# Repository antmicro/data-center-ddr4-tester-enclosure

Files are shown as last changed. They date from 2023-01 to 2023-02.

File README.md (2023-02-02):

# Data Center DDR4 Tester Enclosure

Copyright (c) 2022-2023 [Antmicro](https://antmicro.com)

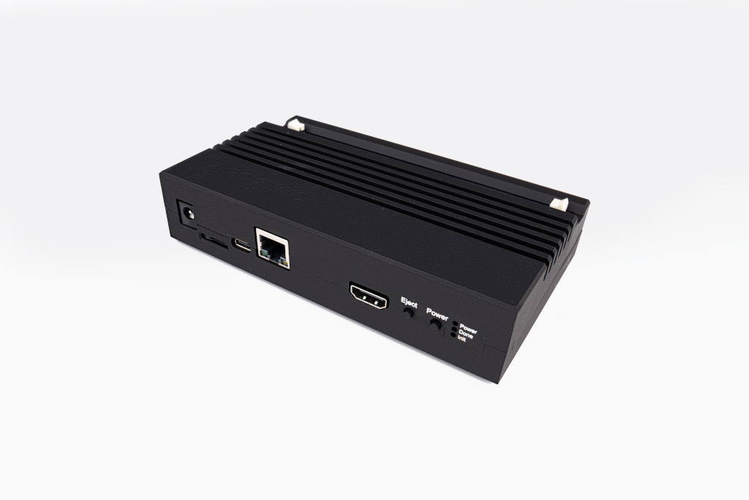
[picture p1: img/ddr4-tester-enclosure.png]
Data Center DDR4 Tester Enclosure


## Overview

This repository contains open hardware mechanical design files for an enclosure matching the [Data Center DRAM Tester](https://github.com/antmicro/data-center-dram-tester) PCBs.
The enclosure has been optimized mechanically for PCBs in revision 1.2.0.
There are three major parts of the enclosure:

* base - supporting the DRAM tester PCB from the bottom,
* front lid - installed above the FPGA, connectors and power supply section of the PCB,
* back lid - installed around the DDR4 RDIMM module slot.

Additionally there are two mechanical components exposing the LEDs installed on the DRAM tester PCB:

* PMMA lightpipe - custom lightpipe laser-cut from acrylic glass (PMMA),
* lightpipe separator - groups LED lightpipes and keeps the custom PMMA lightpipes from stray light.

## Repository structure

The main repository directory contains a LICENSE and a README.
The remaining files are stored in the following directories:

* `step` - contains the enclosure parts published as STEP files 
* `stl` - contains the enclosure parts for 3D printing in STL format
* `dxf` - contains the production file for PMMA laser cutting
* `img` - contains graphics for this README

## Key features

* Dust protection
* Improves passive cooling of the FPGA 
* Optimized for desktop usage

## License

[Apache-2.0](LICENSE)

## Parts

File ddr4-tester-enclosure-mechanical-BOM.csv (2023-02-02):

Description | Quantity | Name | Finish | Material | Manufacturer | MPN
Enclosure base | 1 | base | Black-anodized | Aluminium | Custom-CNC milled | -
Enclosure back lid | 1 | back_lid | Black-anodized | Aluminium | Custom-CNC milled | -
Enclosure front lid | 1 | front_lid | Black-anodized | Aluminium | Custom-CNC milled | -
Light guides | 6 | PMMA_lightpipe | Transparent or frosted | PMMA | Custom-Laser cut | -
Light guide separator | 1 | lightpipe_separator | Any | PLA, PETG,ABS | Custon -3D print | -
Enclosure bolts | 4 | Bolt M3x8 | Black-anodized | Steel | KRAFTBERG | M3X8/D7985B
Light guide separator bolts | 2 | Bolt M3x4 | Black-anodized | Steel | KRAFTBERG | M3X4/D7985B
Status diodes light pipe | 1 | Light pipe | - | PC clear | Mentor | 1296.2013
Rubber legs | 4 | rubber legs | black | Rubber | FIX&FASTEN | RF8-2A
Thermal paste | 1 | - | - | - | - | -

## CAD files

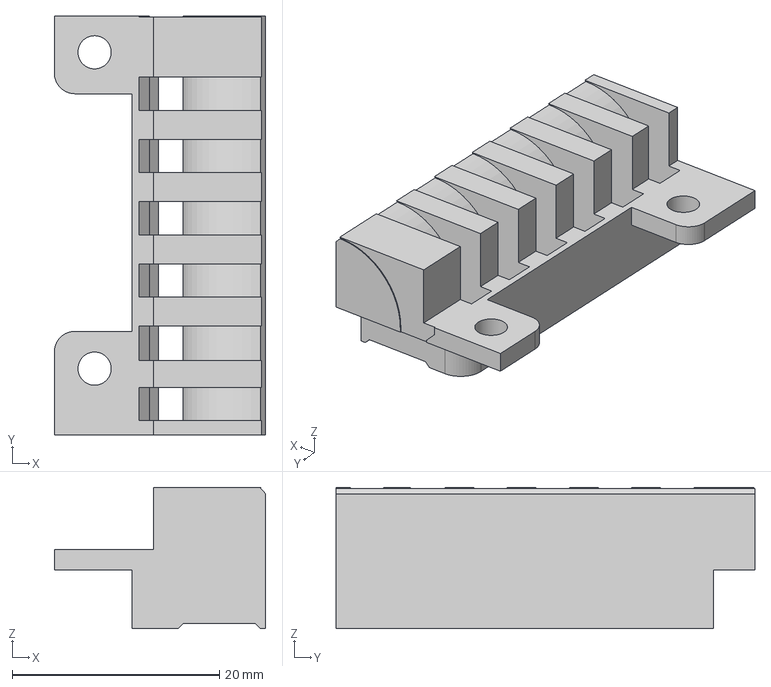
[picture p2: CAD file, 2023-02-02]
step/lightpipe_separator.step
20.4 x 40.4 x 13.6 mm

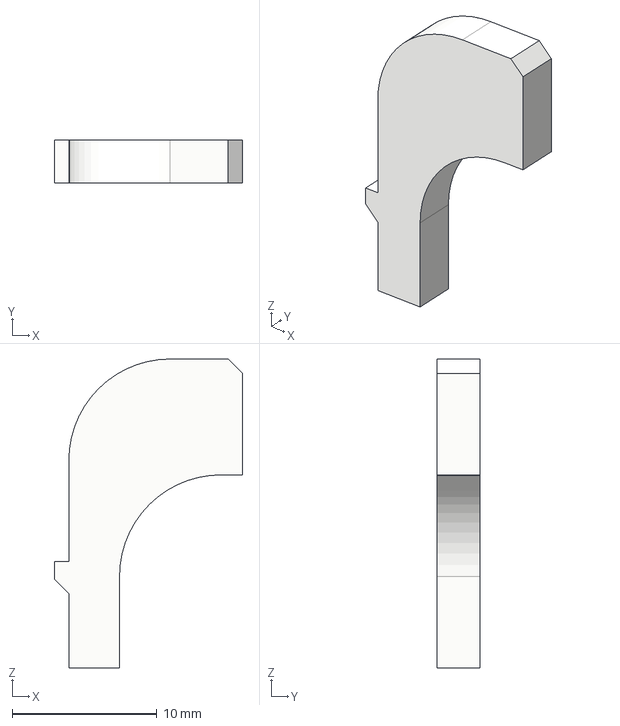
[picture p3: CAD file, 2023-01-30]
step/PMMA_lightpipe.step
13.0 x 3.00 x 21.3 mm

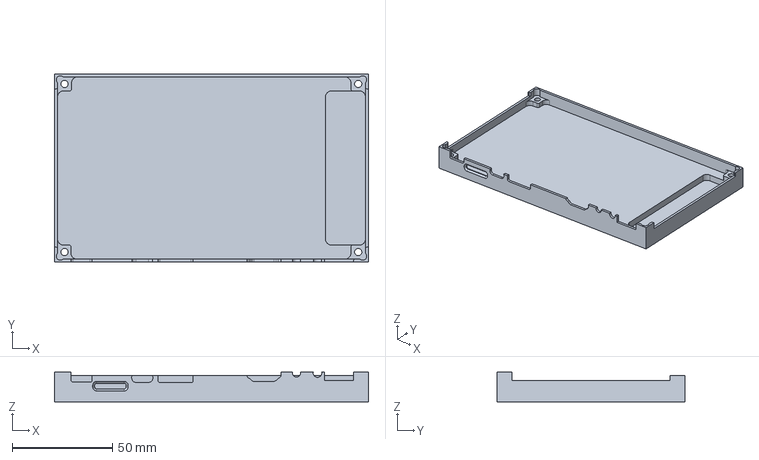
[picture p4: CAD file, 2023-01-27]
step/base.step
156.9 x 94.0 x 14.8 mm

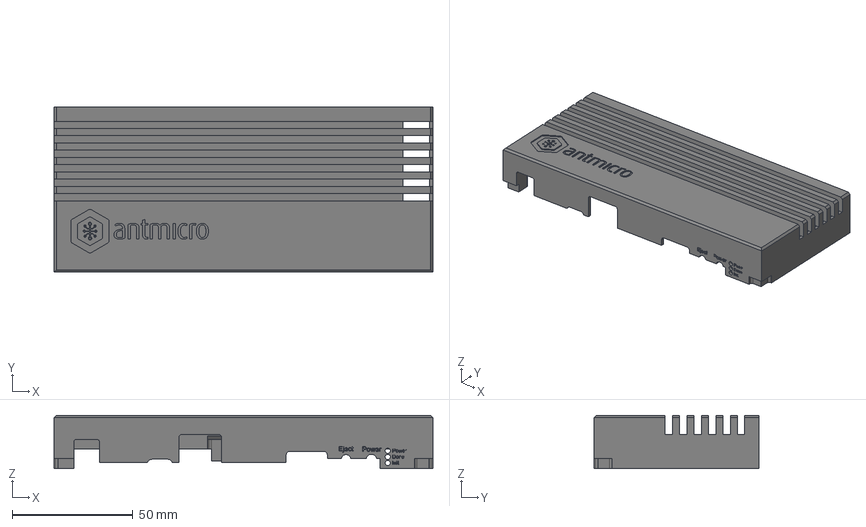
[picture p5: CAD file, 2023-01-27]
step/front_lid.step
156.9 x 68.5 x 22.1 mm

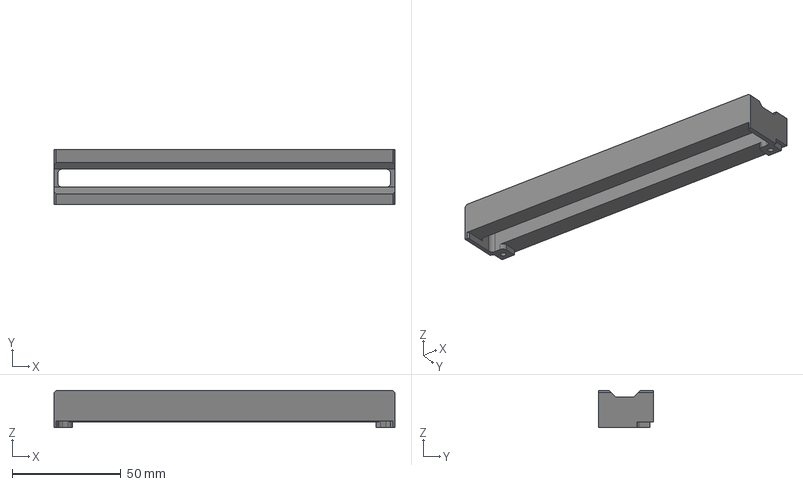
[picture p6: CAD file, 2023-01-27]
step/back_lid.step
156.9 x 25.5 x 17.1 mm

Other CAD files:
dxf/PMMA_lightpipe.dxf
stl/lightpipe_separator.stl

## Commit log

2023-01-27 Add STEP files
    [back_lid.step, base.step, front_lid.step]
2023-01-30 Add lightpipe and lightpipe_separator steps
    [PMMA_lightpipe.step, lightpipe_separator.step]
2023-01-30 Add dxf production files
    [PMMA_lightpipe.dxf]
2023-01-30 Add stl parts for 3D printing
    [lightpipe_separator.stl]
2023-02-02 Update lightpipe_separator files
    [lightpipe_separator.step, lightpipe_separator.stl]
2023-02-02 Add bill of materials
    [ddr4-tester-enclosure-mechanical-BOM.csv]
